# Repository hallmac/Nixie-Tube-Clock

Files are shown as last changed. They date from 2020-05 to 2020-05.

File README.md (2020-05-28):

# Nixie-Tube-Clock

## Purpose

This project is part of the Oregon State Retro Electronics Club 2019-20 yearly club effort. This project aims to bring the warm Soviet glow of Nixie Tubes into the homes of all that invite it. This project delivers a simple, easy to assemble PCB that allows for a genuine Soviet Nixie Tube experience for about $100.

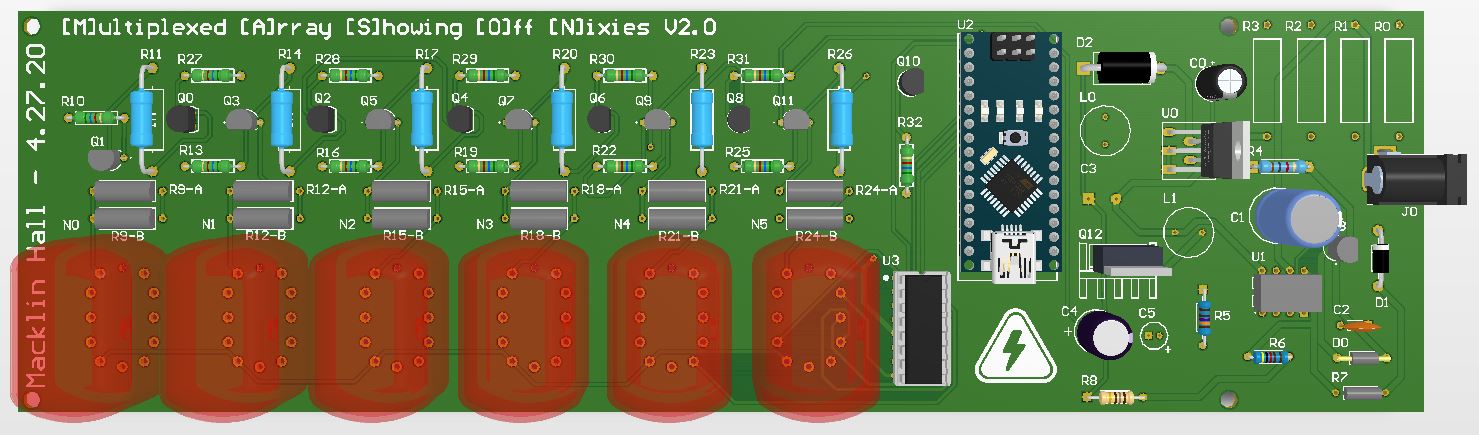
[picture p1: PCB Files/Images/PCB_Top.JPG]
PCB_TOP

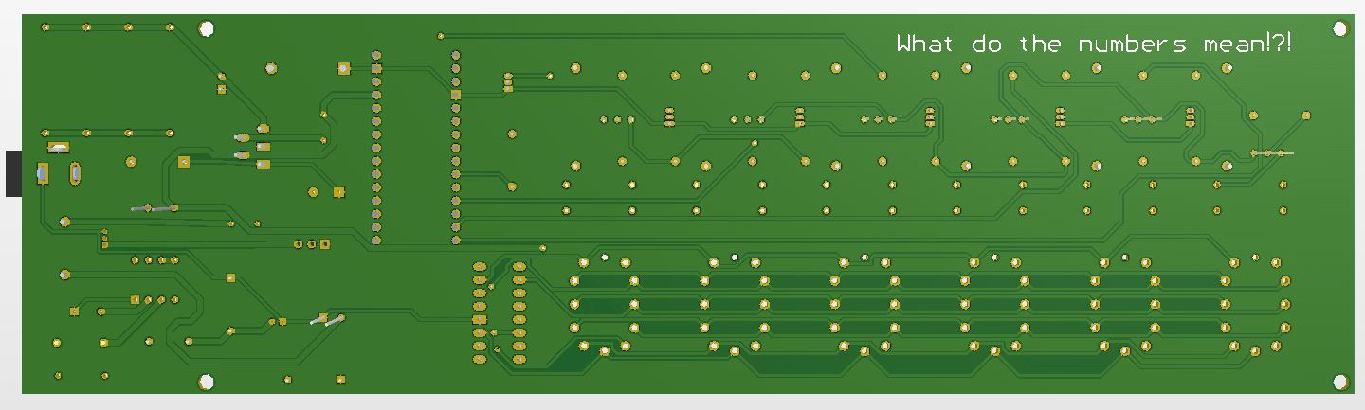
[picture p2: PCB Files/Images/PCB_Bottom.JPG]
PCB_BOTTOM


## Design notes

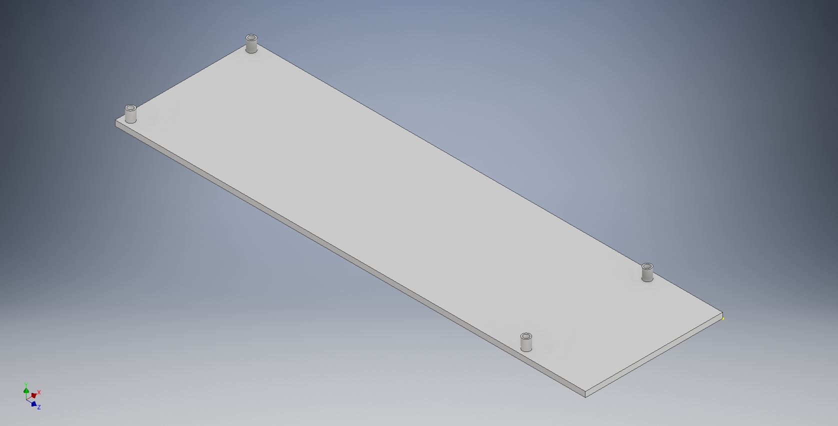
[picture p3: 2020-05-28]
Enclosure Design Files/Nixie Base.jpg

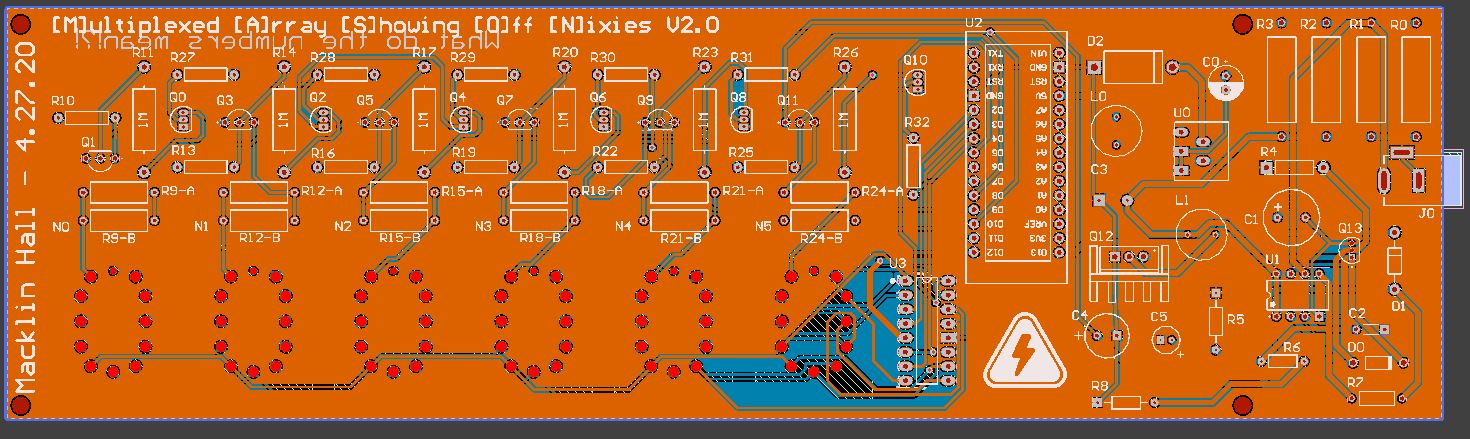
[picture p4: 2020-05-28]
PCB Files/Images/PCB_Layer_Top.JPG

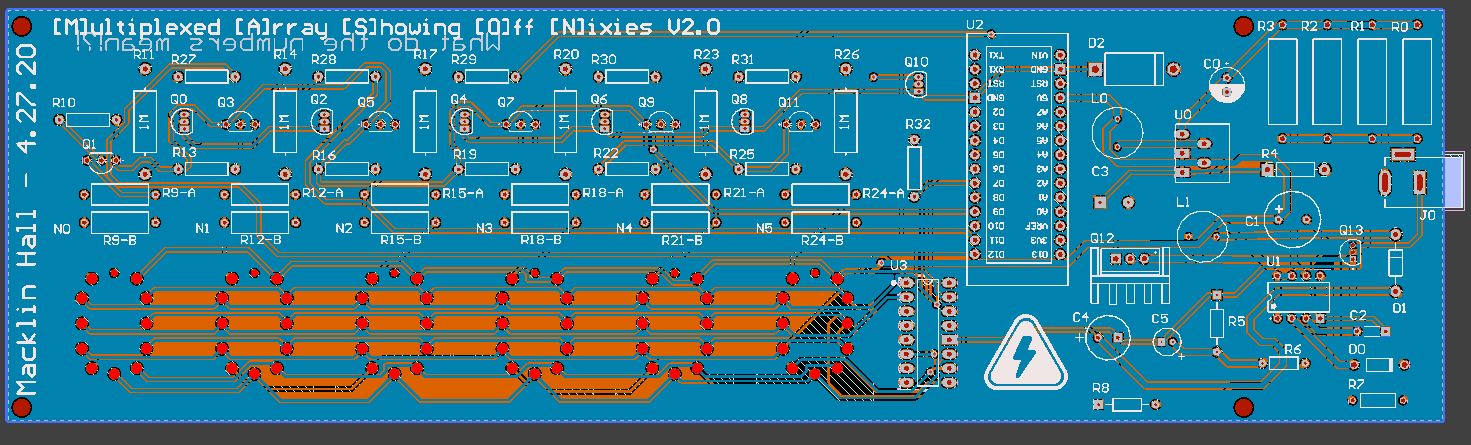
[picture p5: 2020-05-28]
PCB Files/Images/PCB_Layer_Bottom.JPG

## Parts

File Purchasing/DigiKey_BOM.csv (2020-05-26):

# | QUANTITY | PART NUMBER | MANUFACTURER PART NUMBER | DESCRIPTION | CUSTOMER REFERENCE | BACKORDER | UNIT PRICE | EXTENDED PRICE
1 | 1 | 497-7413-5-ND | MC34063ACN | IC REG BUCK BST ADJ 1.5A 8DIP | U1 | 0 | 0.78000 | 0.78
2 | 1 | LM2576TV-012GOS-ND | LM2576TV-012G | IC REG MULT CONFG 12V 3A TO220-5 | U0 | 0 | 2.05000 | 2.05
3 | 1 | 2057-ICS-316-T-ND | ICS-316-T | IC SOCKET, DIP, 16P 2.54MM PITCH | U3 | 0 | 0.18000 | 0.18
4 | 6 | 1MZCT-ND | FMP200JR-52-1M | RES 1M OHM 2W 5% AXIAL | R11, R14, R17, R20, R23, R26 | 0 | 0.34000 | 2.04
5 | 1 | CF12JT180RCT-ND | CF12JT180R | RES 180 OHM 1/2W 5% AXIAL | R8 | 0 | 0.10000 | 0.10
6 | 1 | 475KXBK-ND | MFR-25FBF52-475K | RES 475K OHM 1/4W 1% AXIAL | R7 | 0 | 0.10000 | 0.10
7 | 1 | 4.02KXBK-ND | MFR-25FBF52-4K02 | RES 4.02K OHM 1/4W 1% AXIAL | R6 | 0 | 0.10000 | 0.10
8 | 1 | 13.7KXBK-ND | MFR-25FBF52-13K7 | RES 13.7K OHM 1/4W 1% AXIAL | R5 | 0 | 0.10000 | 0.10
9 | 1 | S1KHCT-ND | CFM12JT1K00 | RES 1K OHM 1/2W 5% CF MINI | R4 | 0 | 0.10000 | 0.10
10 | 1 | 497-2757-5-ND | IRF630 | MOSFET N-CH 200V 9A TO-220 | Q12 | 0 | 1.04000 | 1.04
11 | 6 | 1514-MPSA92PBFREE-ND | MPSA92 PBFREE | TRANS PNP 300V 0.5A TO-92 | Q1, Q3, Q5, Q7, Q9, Q11 | 0 | 0.48000 | 2.88
12 | 6 | MPSA42FS-ND | MPSA42 | TRANS NPN 300V 0.5A TO-92 | Q0, Q2, Q4, Q6, Q8, Q10 | 0 | 0.44000 | 2.64
13 | 2 | RLB9012-101KL-ND | RLB9012-101KL | FIXED IND 100UH 1.4A 280 MOHM TH | L0, L1 | 0 | 0.72000 | 1.44
14 | 1 | 1N5822GOS-ND | 1N5822G | DIODE SCHOTTKY 40V 3A DO201AD | D2 | 0 | 0.43000 | 0.43
15 | 1 | 2092-KLDX-0202-B-ND | KLDX-0202-B | CONN PWR JACK 2.5X5.5MM SOLDER | J0 | 0 | 0.53000 | 0.53
16 | 1 | BAV21-TAPGICT-ND | BAV21-TAP | DIODE GEN PURP 200V 250MA DO35 | D1 | 0 | 0.17000 | 0.17
17 | 1 | 1N914CT-ND | 1N914TR | DIODE GEN PURP 100V 200MA DO35 | D0 | 0 | 0.10000 | 0.10
18 | 1 | 732-8883-1-ND | 860021373005 | CAP ALUM 3.3UF 20% 400V RADIAL | C4 | 0 | 0.28000 | 0.28
19 | 1 | 732-8847-1-ND | 860020672001 | CAP ALUM 0.1UF 20% 50V RADIAL | C5 | 0 | 0.10000 | 0.10
20 | 1 | 732-8634-1-ND | 860010473011 | CAP 220 UF 20% 25 V | C3 | 0 | 0.21000 | 0.21
21 | 1 | 732-8630-1-ND | 860010473007 | CAP 100 UF 20% 25 V | C0 | 0 | 0.12000 | 0.12
22 | 1 | BC2690CT-ND | K681K10X7RF5UH5 | CAP CER 680PF 50V X7R RADIAL | C2 | 0 | 0.22000 | 0.22
23 | 1 | 399-6603-ND | ESK108M025AH4AA | CAP ALUM 1000UF 20% 25V RADIAL | C1 | 0 | 0.47000 | 0.47
24 | 12 | RNF14FTD10K0CT-ND | RNF14FTD10K0 | RES 10K OHM 1/4W 1% AXIAL | R10, 13, 16, 19, 22, 25, 27, 28, 29, 30, 31, 32 | 0 | 0.07200 | 0.86
25 | 12 | P20KW-2CT-ND | ERG-2SJ203V | RES 20K OHM 2W 5% AXIAL | R9, R12, R15, R18, R21, R24 | 0 | 0.26900 | 3.23
26 | 4 | RSMF2JT1R00CT-ND | RSMF2JT1R00 | RES 1 OHM 2W 5% AXIAL | R0, R1, R2, R3 | 0 | 0.28000 | 1.12
27 | 2 | 1212-1099-ND | 310-87-110-41-001101 | CONN SOCKET 10POS 0.1 GOLD PCB | U2 | 0 | 0.62000 | 1.24
28 | 1 | 1939-1996-ND | WR95E2000LCP-F(R6B) | AC/DC WALL MOUNT ADAPTER 12V 24W |  | 0 | 11.57000 | 11.57

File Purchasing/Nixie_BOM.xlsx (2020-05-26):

Comment | Designator | URL | Price Per Unit | Quantity | Total Price
100uF | C0 | https://www.digikey.com/product-detail/en/w%C3%BCrth-elektronik/860010473007/732-8630-1-ND/5728586 | 0.12 | 1 | 0.12
1000uF | C1 | https://www.digikey.com/product-detail/en/kemet/ESK108M025AH4AA/399-6603-ND/3083018 | 0.47 | 1 | 0.47
680pF | C2 | https://www.digikey.com/product-detail/en/vishay-bc-components/K681K10X7RF5UH5/BC2690CT-ND/2356904 | 0.22 | 1 | 0.22
220uF | C3 | https://www.digikey.com/product-detail/en/w%C3%BCrth-elektronik/860010473011/732-8634-1-ND/5728590 | 0.21 | 1 | 0.21
3.3uF | C4 | https://www.digikey.com/product-detail/en/w%C3%BCrth-elektronik/860021373005/732-8883-1-ND/5728828 | 0.28 | 1 | 0.28
0.1uF | C5 | https://www.digikey.com/product-detail/en/w%C3%BCrth-elektronik/860020672001/732-8847-1-ND/5728792 | 0.1 | 1 | 0.1
1N914 | D0 | https://www.digikey.com/product-detail/en/on-semiconductor/1N914TR/1N914CT-ND/458920 | 0.1 | 1 | 0.1
BAV21 | D1 | https://www.digikey.com/product-detail/en/vishay-semiconductor-diodes-division/BAV21-TAP/BAV21-TAPGICT-ND/8564481 | 0.17 | 1 | 0.17
1N5822 | D2 | https://www.digikey.com/product-detail/en/on-semiconductor/1N5822G/1N5822GOS-ND/1474217 | 0.43 | 1 | 0.43
JACK DC | J0 | https://www.digikey.com/product-detail/en/KLDX-0202-B/2092-KLDX-0202-B-ND/9990096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 | 0.53 | 1 | 0.53
100uH | L0, L1 | https://www.digikey.com/product-detail/en/bourns-inc/RLB9012-101KL/RLB9012-101KL-ND/1969604 | 0.72 | 2 | 1.44
MPSA42 | Q0, Q2, Q4, Q6, Q8, Q10 | https://www.digikey.com/product-detail/en/on-semiconductor/MPSA42/MPSA42FS-ND/32397 | 0.44 | 6 | 2.64
MPSA92 | Q1, Q3, Q5, Q7, Q9, Q11 | https://www.digikey.com/product-detail/en/central-semiconductor-corp/MPSA92-PBFREE/1514-MPSA92PBFREE-ND/4806936 | 0.48 | 6 | 2.88
IRF630 | Q12 | https://www.digikey.com/product-detail/en/IRF630/497-2757-5-ND/603782/?itemSeq=324557714 | 1.04 | 1 | 1.04
1 Ohm | R0, R1, R2, R3 | https://www.digikey.com/product-detail/en/RSMF2JT1R00/RSMF2JT1R00CT-ND/2021849/?itemSeq=324715456 | 0.28 | 4 | 1.12
1K Ohm | R4 | https://www.digikey.com/product-detail/en/stackpole-electronics-inc/CFM12JT1K00/S1KHCT-ND/2617564 | 0.1 | 1 | 0.1
13.7K Ohm | R5 | https://www.digikey.com/product-detail/en/MFR-25FBF52-13K7/13.7KXBK-ND/13244/?itemSeq=324557469 | 0.1 | 1 | 0.1
4.02K Ohm | R6 | https://www.digikey.com/product-detail/en/yageo/MFR-25FBF52-4K02/4-02KXBK-ND/13143 | 0.1 | 1 | 0.1
475K Ohm | R7 | https://www.digikey.com/product-detail/en/yageo/MFR-25FBF52-475K/475KXBK-ND/13652 | 0.1 | 1 | 0.1
180 Ohm | R8 | https://www.digikey.com/product-detail/en/stackpole-electronics-inc/CF12JT180R/CF12JT180RCT-ND/1830469 | 0.1 | 1 | 0.1
20K Ohm | R9, R12, R15, R18, R21, R24 | https://www.digikey.com/product-detail/en/ERG-2SJ203V/P20KW-2CT-ND/3982566/?itemSeq=324713725 | 0.269 | 6 | 1.614
10K Ohm | R10, R13, R16, R19, R22, R25, R27, R28, R29, R30, R31, R32 | https://www.digikey.com/product-detail/en/RNF14FTD10K0/RNF14FTD10K0CT-ND/1975090/?itemSeq=324713295 | 0.072 | 12 | 0.864
1M Ohm | R11, R14, R17, R20, R23, R26 | https://www.digikey.com/product-detail/en/yageo/FMP200JR-52-1M/1MZCT-ND/2058981 | 0.34 | 6 | 2.04
LM2576TV-012G | U0 | https://www.digikey.com/product-detail/en/LM2576TV-012G/LM2576TV-012GOS-ND/1476734/?itemSeq=324556715 | 2.05 | 1 | 2.05
MC34063ACN | U1 | https://www.digikey.com/product-detail/en/MC34063ACN/497-7413-5-ND/1038909/?itemSeq=324556710 | 0.78 | 1 | 0.78
SN74141 Socket | U3 | https://www.digikey.com/product-detail/en/ICS-316-T/2057-ICS-316-T-ND/9832862/?itemSeq=324557183 | 0.18 | 1 | 0.18
Nano Socket | U2 Socket | https://www.digikey.com/product-detail/en/310-87-110-41-001101/1212-1099-ND/3757349/?itemSeq=325035529 | 0.62 | 2 | 1.24
Power Supply |  | https://www.digikey.com/product-detail/en/WR95E2000LCP-F(R6B)/1939-1996-ND/10187578/?itemSeq=325036912 | 11.57 | 1 | 11.57
Shipping + Tariff |  |  | 11.18 | 1 | 11.18 | Digikey Total | 43.768
Components | Digikey Total |  | 43.768 | 1 | 43.768
IN12 | N0, N1, N2, N3, N4, N5 | https://www.ebay.com/itm/6-pcs-IN-12B-NEW-TESTED-Nixie-Tubes-For-Clock-Kit-Soviet-OTK-TESTING-VIDEO/272121625749 | 22.5 | 1 | 22.5
MPSA55 | Q13 | https://www.ebay.com/itm/SEMI-TO-92-TRANSISTOR-MPSA55-USED-IN-VARIOUS-APPLICATIONS/184260847094 | 1.59 | 1 | 1.59
SN74141 | U3 | https://www.ebay.com/itm/K155ID1-SN-74141-IC-Driver-for-Nixie-tubes/352621483832 | 4.8 | 1 | 4.8
Arduino Nano | U2 | https://www.ebay.com/itm/1PCS-Promotion-For-arduino-Nano-3-0-Atmega328-Controller-Compatible-Board-WAVGAT/313067607824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 | 5.12 | 1 | 5.12
PCBs |  | https://cart.jlcpcb.com/?edaOrderUrl=https:%2F%2Feasyeda.com%2Forder&electropolishingOnlyNo=no&achieveDate=72 | 25.46 | 1 | 25.46
 |  |  | PROJECT TOTAL |  | 103.238

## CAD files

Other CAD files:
Enclosure Design Files/Base.dwg
Enclosure Design Files/Base.ipt

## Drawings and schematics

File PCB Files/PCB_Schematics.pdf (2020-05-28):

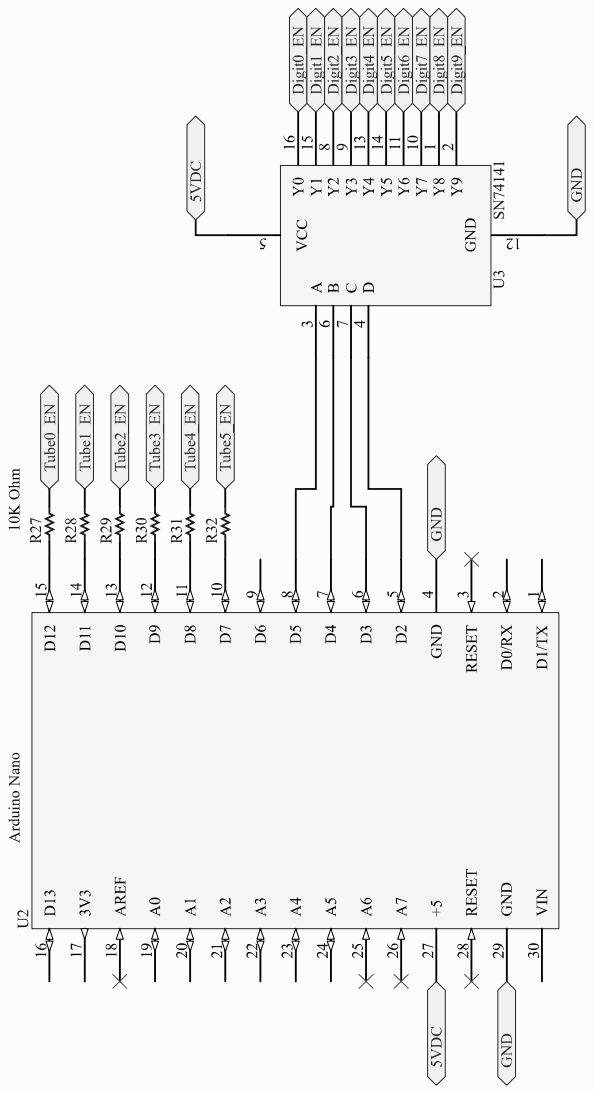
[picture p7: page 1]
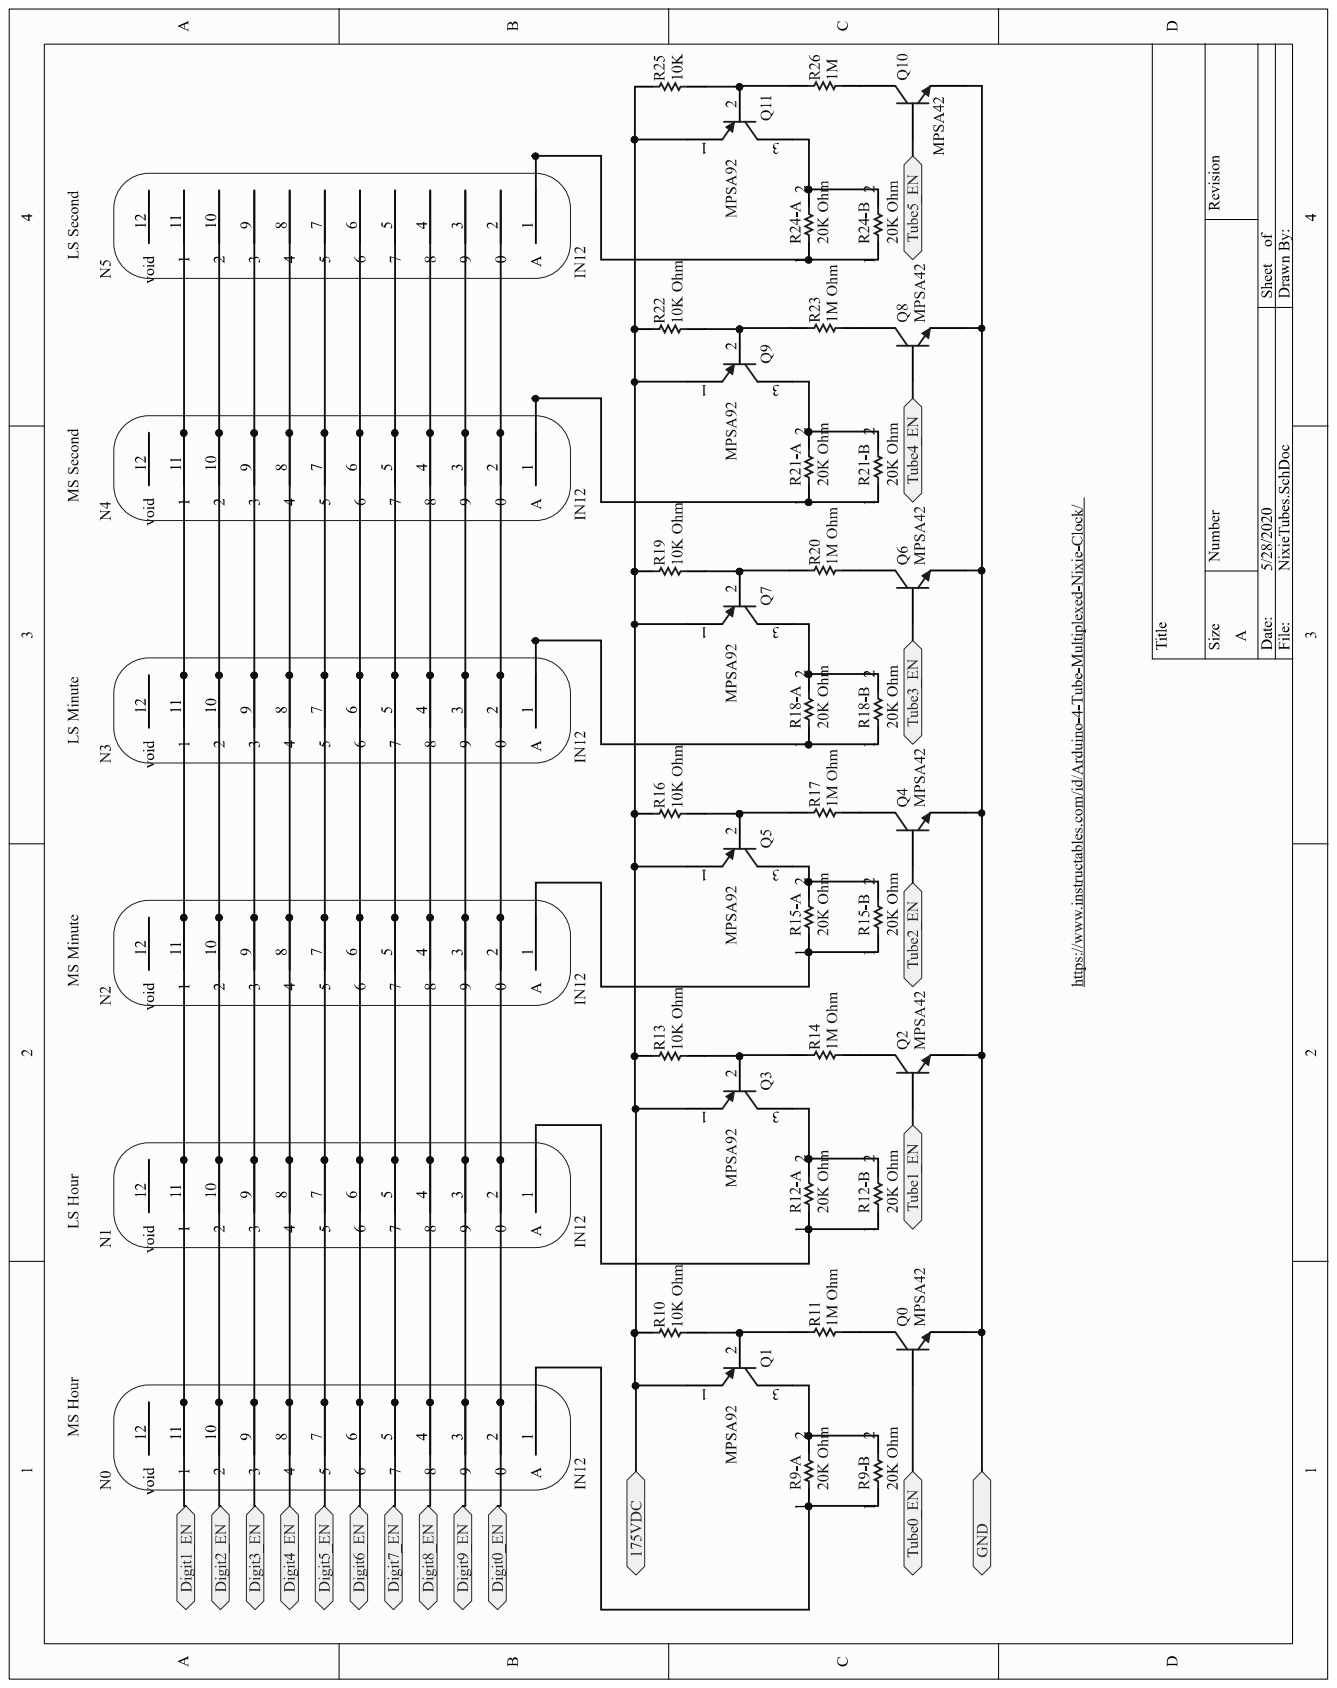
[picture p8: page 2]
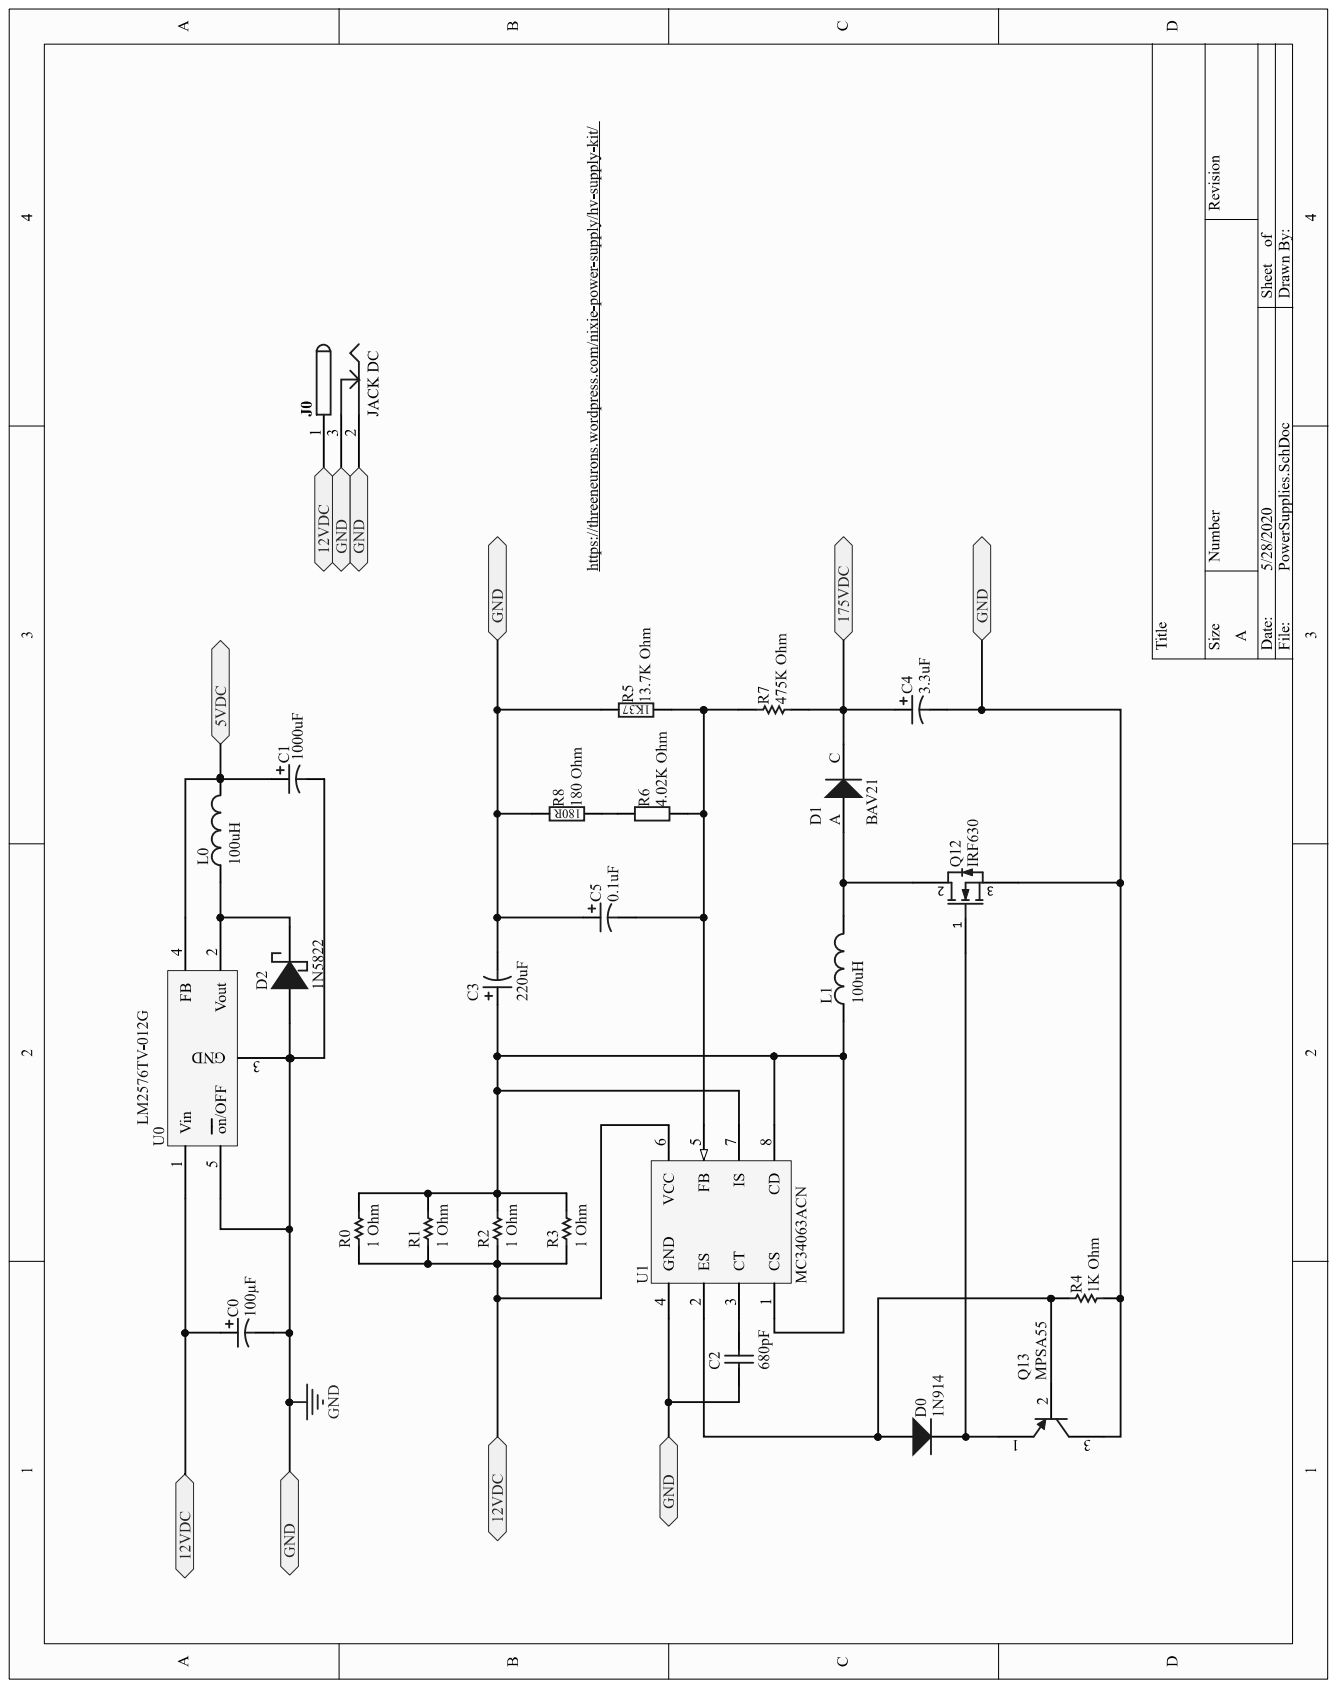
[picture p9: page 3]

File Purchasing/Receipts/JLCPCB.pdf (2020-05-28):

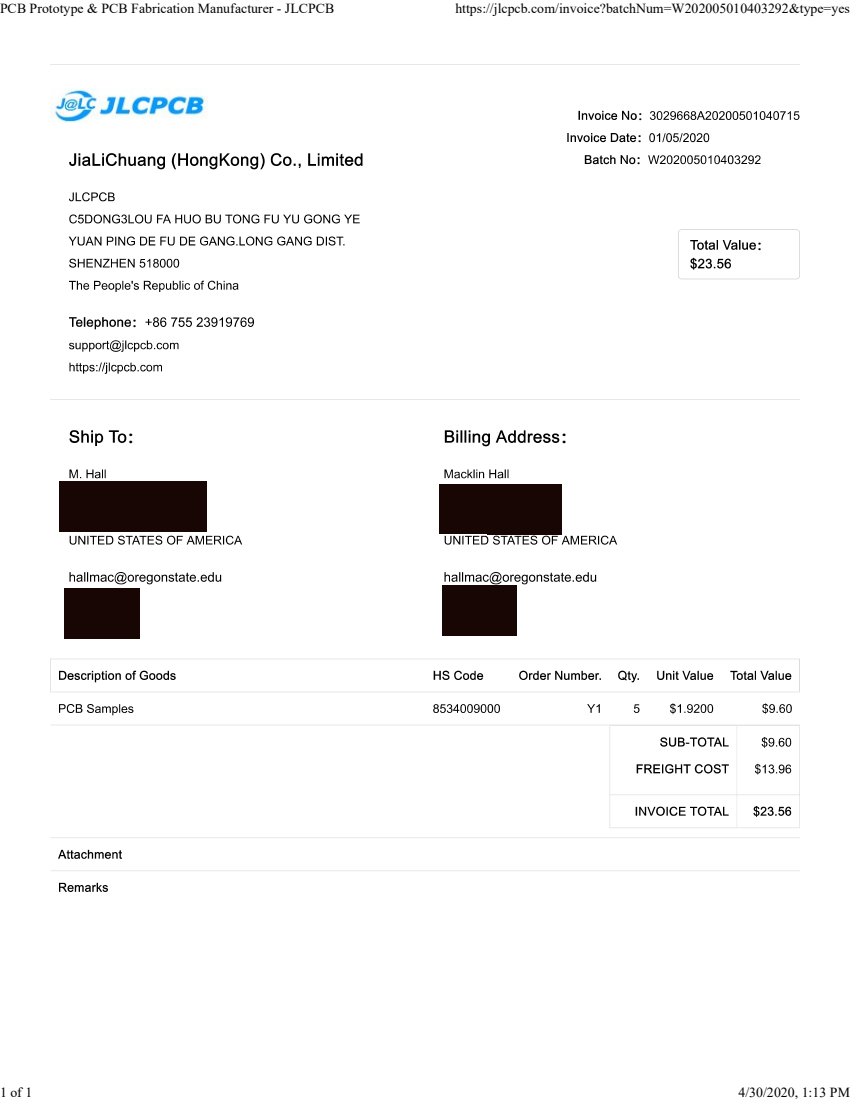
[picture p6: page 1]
PCB Prototype & PCB Fabrication Manufacturer - JLCPCB; https://jlcpcb.com/invoice?batchNum=W202005010403292&type=yes
